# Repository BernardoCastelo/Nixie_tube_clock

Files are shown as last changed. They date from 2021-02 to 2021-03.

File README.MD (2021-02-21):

# Cold cathode display clock

## Components:
> - IN12 displays
> - Firebeetle ESP-32
> - NTE74141 BCD−to−Decimal Decoder
> - 74HC4094N 8-bit Shift Register

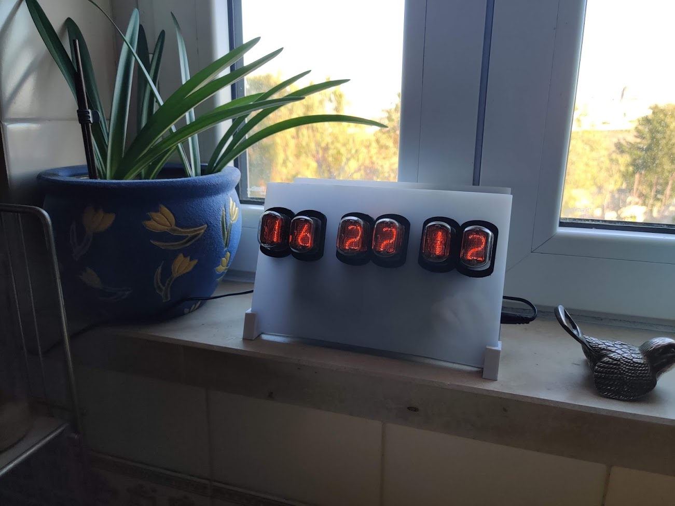
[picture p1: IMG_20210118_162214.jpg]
preview


- https://photos.app.goo.gl/ndDG4vCSE8pfqmn36

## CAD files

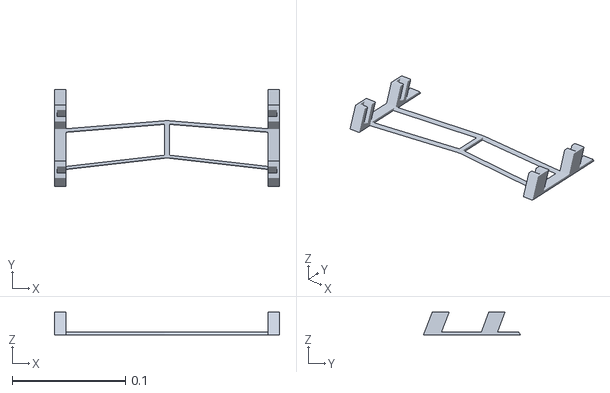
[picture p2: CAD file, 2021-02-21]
03.3DPrintedBase/Base.stl
0.199 x 0.0859 x 0.02

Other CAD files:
03.3DPrintedBase/Base.blend

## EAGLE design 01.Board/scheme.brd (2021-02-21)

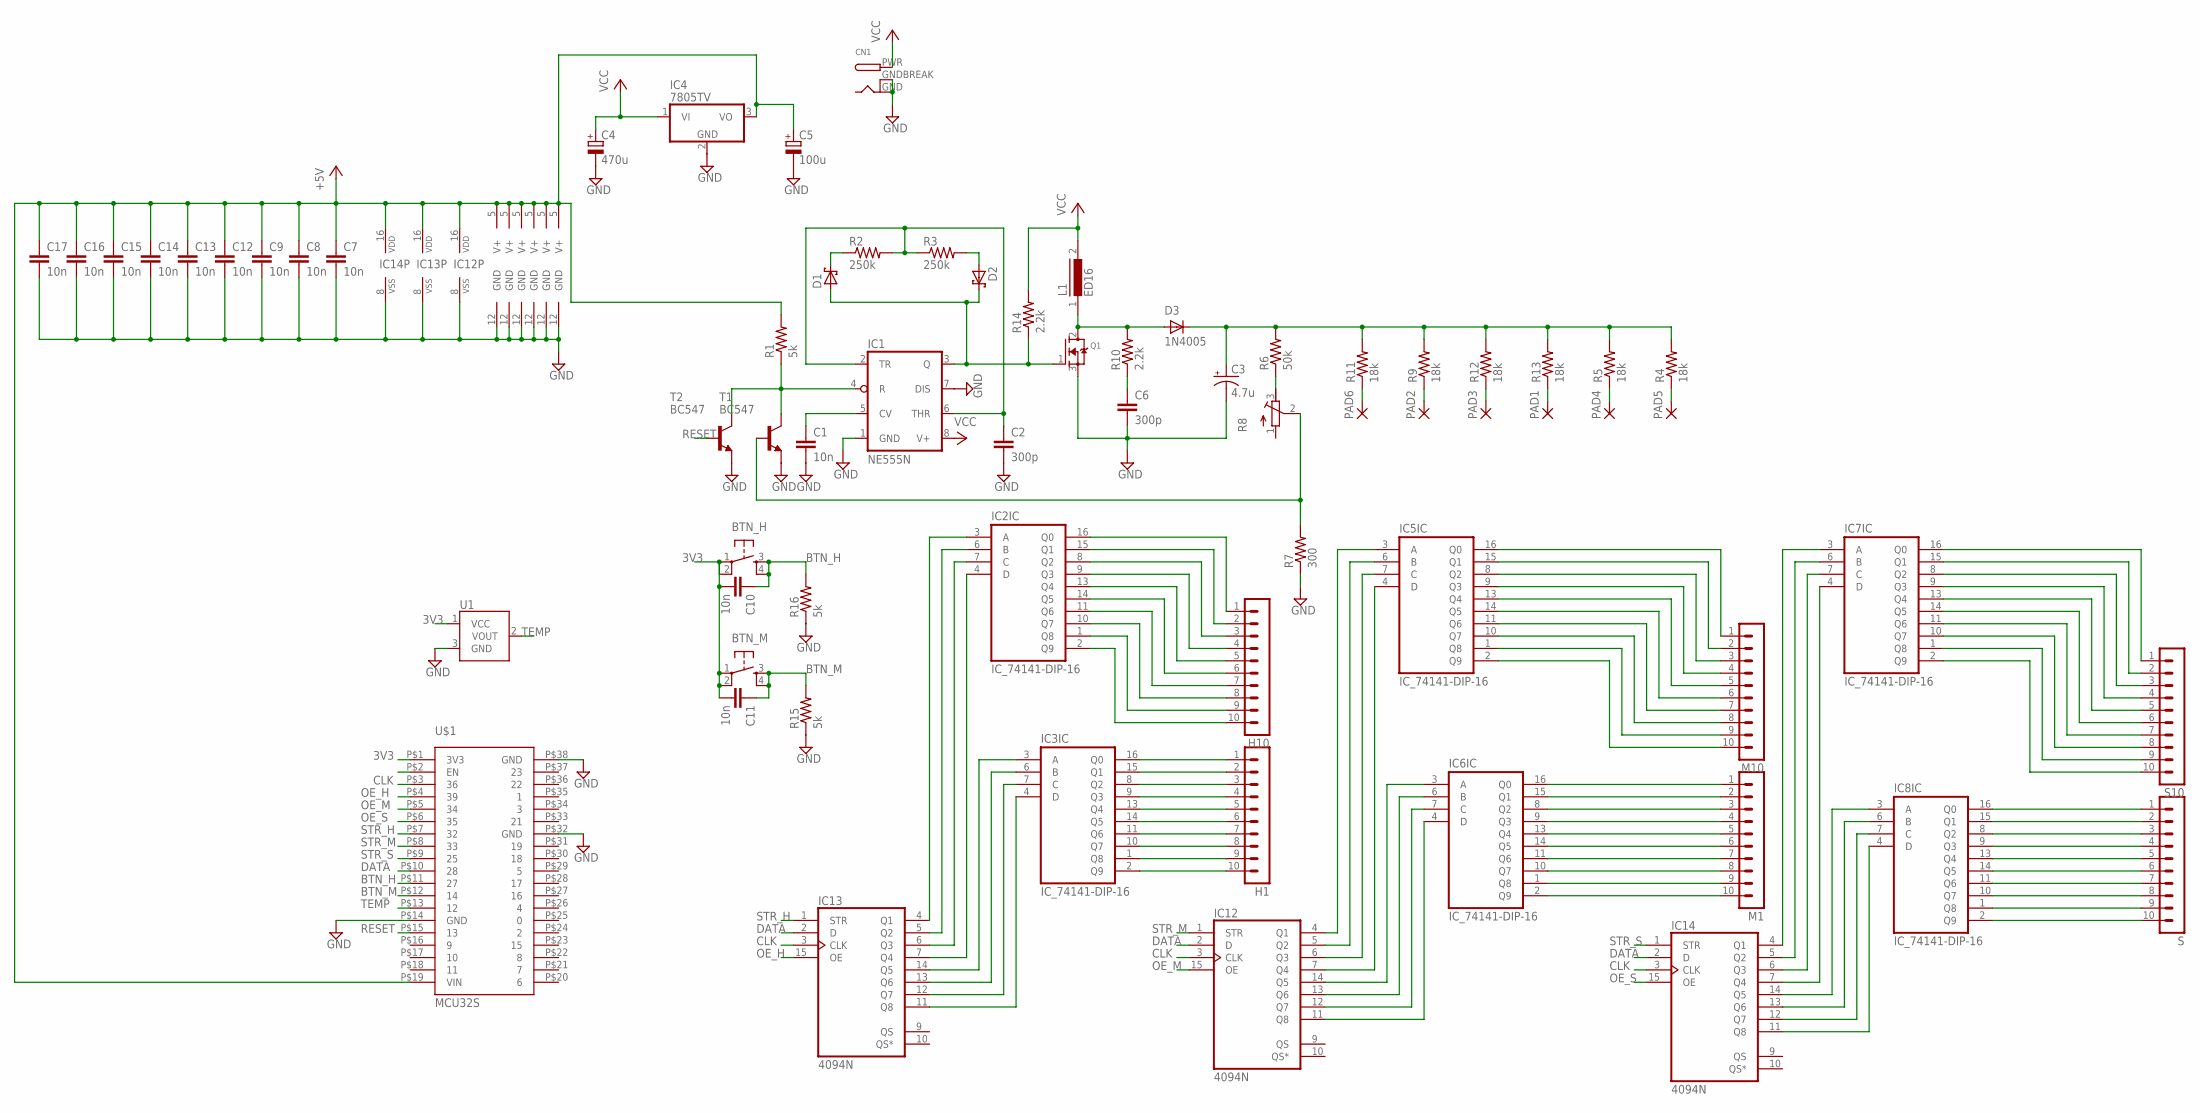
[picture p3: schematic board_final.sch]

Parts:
BTN_H: TAC_SWITCHPTH; TACTILE-PTH
BTN_M: TAC_SWITCHPTH; TACTILE-PTH
C1, C7, C8, C9, C10, C11, C12, C13, C14, C15, C16, C17: 10n; C050-030X075
C2, C6: 300p; C050-030X075
C3: 4.7u; E3,5-10
C4: 470u; E5-8,5
C5: 100u; E5-8,5
CN1: DCBARRELPTH; DCJACK_2MM_PTH
D1, D2: SCHOTTKY-DIODEF126Z12; F126Z12
D3: 1N4005; DO41-10
H1, H10: MA10-1
IC1: NE555N; DIL08
IC2, IC3, IC5, IC6, IC7, IC8: IC_74141-DIP-16; DIL16
IC4: 7805TV; TO220V
IC12, IC13, IC14: 4094N; DIL16
L1: ED16
M1, M10: MA10-1
PAD1, PAD2, PAD3, PAD4, PAD5, PAD6: 3,17/1,3
Q1: MOSFET-NGDS_TO220V; TO220V
R1, R15, R16: 5k; 0207/10
R2, R3: 250k; 0207/10
R4, R5, R9, R11, R12, R13: 18k; 0207/10
R6: 50k; 0207/10
R7: 300; 0207/10
R8: R-TRIMM3296W; RTRIM3296W
R10, R14: 2.2k; 0207/10
S, S10: MA10-1
T1, T2: BC547; TO92
U1: TMP36GT9; TO-92
U$1: MCU32S; NODEMCU32S

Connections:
3V3: BTN_H.1, BTN_H.2, BTN_M.1, BTN_M.2, C10.2, C11.2, U1.1 (VCC), U$1.P$1 (3V3)
BTN_H: BTN_H.3, BTN_H.4, C10.1, R16.2, U$1.P$11 (27)
BTN_M: BTN_M.3, BTN_M.4, C11.1, R15.2, U$1.P$12 (14)
CLK: IC12.3 (CLK), IC13.3 (CLK), IC14.3 (CLK), U$1.P$3 (36)
DATA: IC12.2 (D), IC13.2 (D), IC14.2 (D), U$1.P$10 (28)
GND: C1.2, C2.2, C3.-, C4.-, C5.-, C6.2, C7.2, C8.2, C9.2, C12.2, C13.2, C14.2, C15.2, C16.2, C17.2, CN1.GND, CN1.GNDBREAK, IC1.1 (GND), IC1.7 (DIS), IC2.12 (GND), IC3.12 (GND), IC4.2 (GND), IC5.12 (GND), IC6.12 (GND), IC7.12 (GND), IC8.12 (GND), IC12.8 (VSS), IC13.8 (VSS), IC14.8 (VSS), Q1.3 (S), R7.1, R15.1, R16.1, T1.1 (E), T2.1 (E), U1.3 (GND), U$1.P$14 (GND), U$1.P$32 (GND), U$1.P$38 (GND)
unnamed: C1.1, IC1.5 (CV)
unnamed: C2.1, IC1.2 (TR), IC1.6 (THR), R2.2, R3.1
unnamed: C3.+, D3.C, R4.2, R5.2, R6.2, R9.2, R11.2, R12.2, R13.2
unnamed: D1.A, D2.C, IC1.3 (Q), Q1.1 (G), R14.1
unnamed: IC1.4 (R), R1.1, T1.3 (C), T2.3 (C)
unnamed: H10.1, IC2.16 (Q0)
unnamed: D2.A, R3.2
unnamed: D1.C, R2.1
unnamed: IC2.3 (A), IC13.4 (Q1)
unnamed: D3.A, L1.1, Q1.2 (D), R10.2
unnamed: H10.2, IC2.15 (Q1)
unnamed: H10.3, IC2.8 (Q2)
unnamed: H10.4, IC2.9 (Q3)
unnamed: H10.5, IC2.13 (Q4)
unnamed: H10.6, IC2.14 (Q5)
unnamed: H10.7, IC2.11 (Q6)
unnamed: H10.8, IC2.10 (Q7)
unnamed: H10.9, IC2.1 (Q8)
unnamed: H10.10, IC2.2 (Q9)
unnamed: PAD6.1, R11.1
unnamed: IC2.7 (C), IC13.6 (Q3)
unnamed: IC2.6 (B), IC13.5 (Q2)
unnamed: IC2.4 (D), IC13.7 (Q4)
unnamed: H1.1, IC3.16 (Q0)
unnamed: H1.2, IC3.15 (Q1)
unnamed: H1.3, IC3.8 (Q2)
unnamed: C6.1, R10.1
unnamed: H1.4, IC3.9 (Q3)
unnamed: H1.5, IC3.13 (Q4)
unnamed: H1.6, IC3.14 (Q5)
unnamed: H1.7, IC3.11 (Q6)
unnamed: R6.1, R8.3 (E)
unnamed: R7.2, R8.2 (S), T1.2 (B)
unnamed: H1.8, IC3.10 (Q7)
unnamed: H1.9, IC3.1 (Q8)
unnamed: H1.10, IC3.2 (Q9)
unnamed: IC3.7 (C), IC13.12 (Q7)
unnamed: IC3.6 (B), IC13.13 (Q6)
unnamed: IC3.4 (D), IC13.11 (Q8)
unnamed: PAD2.1, R9.1
unnamed: IC3.3 (A), IC13.14 (Q5)
unnamed: IC6.2 (Q9), M1.10
unnamed: IC6.1 (Q8), M1.9
unnamed: IC6.10 (Q7), M1.8
unnamed: IC6.11 (Q6), M1.7
unnamed: IC6.14 (Q5), M1.6
unnamed: IC6.13 (Q4), M1.5
unnamed: IC6.9 (Q3), M1.4
unnamed: IC6.8 (Q2), M1.3
unnamed: IC6.15 (Q1), M1.2
unnamed: IC6.16 (Q0), M1.1
unnamed: IC5.7 (C), IC12.6 (Q3)
unnamed: IC5.6 (B), IC12.5 (Q2)
unnamed: IC5.4 (D), IC12.7 (Q4)
unnamed: PAD3.1, R12.1
unnamed: IC5.3 (A), IC12.4 (Q1)
unnamed: IC5.16 (Q0), M10.1
unnamed: IC5.15 (Q1), M10.2
unnamed: IC5.8 (Q2), M10.3
unnamed: IC5.9 (Q3), M10.4
unnamed: IC5.13 (Q4), M10.5
unnamed: IC5.14 (Q5), M10.6
unnamed: IC5.11 (Q6), M10.7
unnamed: IC5.10 (Q7), M10.8
unnamed: IC5.1 (Q8), M10.9
unnamed: IC5.2 (Q9), M10.10
unnamed: IC6.6 (B), IC12.13 (Q6)
unnamed: IC8.16 (Q0), S.1
unnamed: IC8.15 (Q1), S.2
unnamed: PAD1.1, R13.1
unnamed: IC6.3 (A), IC12.14 (Q5)
unnamed: IC7.3 (A), IC14.4 (Q1)
unnamed: IC8.8 (Q2), S.3
unnamed: IC8.9 (Q3), S.4
unnamed: IC8.13 (Q4), S.5
unnamed: IC8.14 (Q5), S.6
unnamed: IC8.11 (Q6), S.7
unnamed: IC8.10 (Q7), S.8
unnamed: IC8.2 (Q9), S.10
unnamed: IC8.1 (Q8), S.9
unnamed: IC7.16 (Q0), S10.1
unnamed: IC7.6 (B), IC14.5 (Q2)
unnamed: IC7.7 (C), IC14.6 (Q3)
unnamed: IC7.4 (D), IC14.7 (Q4)
unnamed: PAD4.1, R5.1
unnamed: IC8.3 (A), IC14.14 (Q5)
unnamed: IC8.6 (B), IC14.13 (Q6)
unnamed: IC7.15 (Q1), S10.2
unnamed: IC7.8 (Q2), S10.3
unnamed: IC7.9 (Q3), S10.4
unnamed: IC7.13 (Q4), S10.5
unnamed: IC7.14 (Q5), S10.6
unnamed: IC7.11 (Q6), S10.7
unnamed: IC7.10 (Q7), S10.8
unnamed: IC7.1 (Q8), S10.9
unnamed: IC7.2 (Q9), S10.10
unnamed: IC8.7 (C), IC14.12 (Q7)
unnamed: IC8.4 (D), IC14.11 (Q8)
unnamed: PAD5.1, R4.1
unnamed: IC6.7 (C), IC12.12 (Q7)
unnamed: IC6.4 (D), IC12.11 (Q8)
OE_H: IC13.15 (OE), U$1.P$4 (39)
OE_M: IC12.15 (OE), U$1.P$5 (34)
OE_S: IC14.15 (OE), U$1.P$6 (35)
RESET: T2.2 (B), U$1.P$15 (13)
STR_H: IC13.1 (STR), U$1.P$7 (32)
STR_M: IC12.1 (STR), U$1.P$8 (33)
STR_S: IC14.1 (STR), U$1.P$9 (25)
TEMP: U1.2 (VOUT), U$1.P$13 (12)
V+: C5.+, C7.1, C8.1, C9.1, C12.1, C13.1, C14.1, C15.1, C16.1, C17.1, IC2.5 (V+), IC3.5 (V+), IC4.3 (VO), IC5.5 (V+), IC6.5 (V+), IC7.5 (V+), IC8.5 (V+), IC12.16 (VDD), IC13.16 (VDD), IC14.16 (VDD), R1.2, U$1.P$19 (VIN)
VCC: C4.+, CN1.PWR, IC1.8 (V+), IC4.1 (VI), L1.2, R14.2

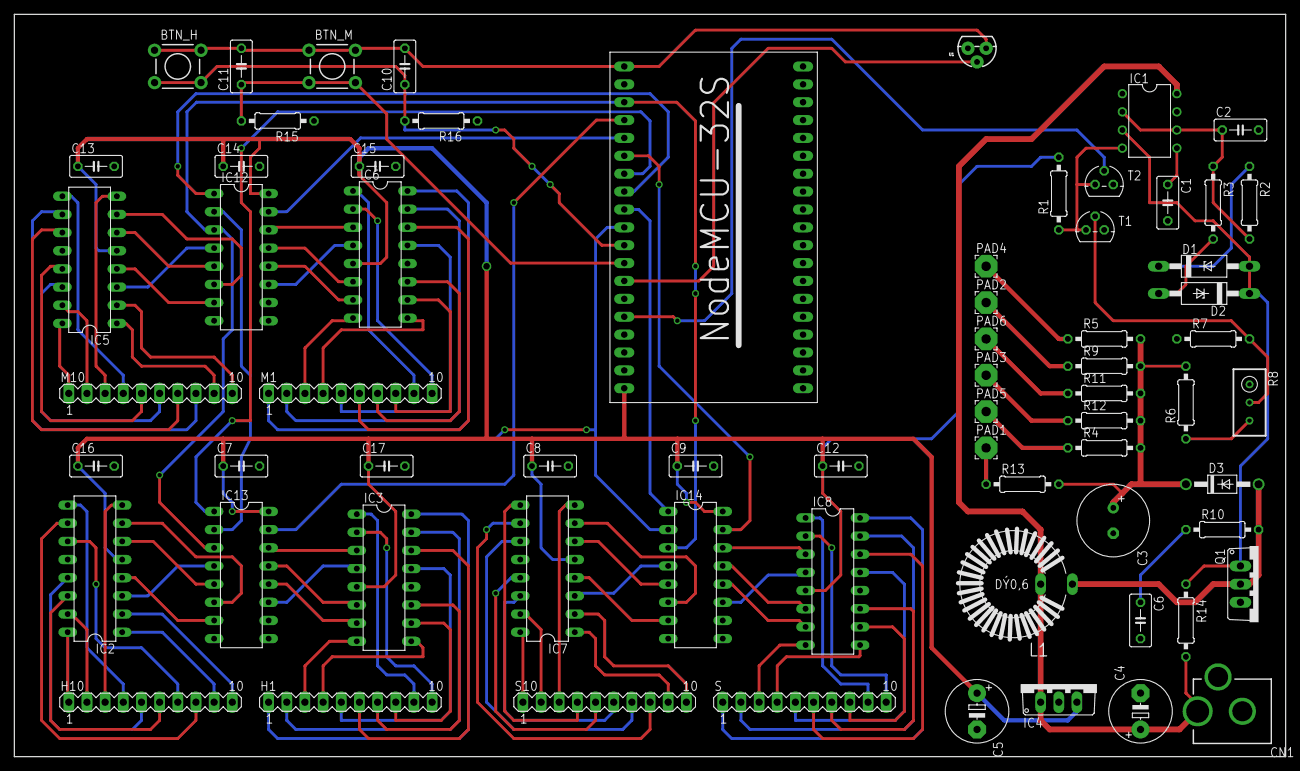
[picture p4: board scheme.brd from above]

Board: 2 copper layers, 177.8 x 103.8 mm, 68 parts (0 on the bottom side), 117 nets.

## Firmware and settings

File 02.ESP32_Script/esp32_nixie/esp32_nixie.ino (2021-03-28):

#include <WiFi.h>
#include "time.h"
#include "constsLib.h"

struct tm timeinfo;
volatile byte hours;
volatile byte minutes;
volatile byte seconds;
volatile int millisValue = 0;
volatile int ntpMillisValue = 0;
volatile bool isShufflingSeconds = false;
volatile bool isShufflingMinutes = false;
volatile bool isShufflingHours = false;
volatile bool isConnecting = false;
volatile int tmpCalc;

void setup()
{
  Serial.begin(9600);
  pinMode(OE_H, OUTPUT);
  pinMode(OE_M, OUTPUT);
  pinMode(OE_S, OUTPUT);
  digitalWrite(OE_H, HIGH);
  digitalWrite(OE_M, HIGH);
  digitalWrite(OE_S, HIGH);

  pinMode(CLK_PIN, OUTPUT);
  pinMode(STR_H, OUTPUT);
  pinMode(STR_M, OUTPUT);
  pinMode(STR_S, OUTPUT);
  pinMode(DATA_PIN, OUTPUT);
  pinMode(RESET, OUTPUT);

  pinMode(BTN_H, INPUT);
  pinMode(BTN_M, INPUT);
  pinMode(TEMP_PIN, INPUT);

  digitalWrite(CLK_PIN, LOW);
  digitalWrite(STR_H, LOW);
  digitalWrite(STR_M, LOW);
  digitalWrite(STR_S, LOW);
  digitalWrite(DATA_PIN, LOW);

  WiFi.begin(ssid, password);
  while (WiFi.status() != WL_CONNECTED)
  {
    delay(500);
    Serial.print(".");
  }
  Serial.println(" CONNECTED");

  configTime(gmtOffset_sec, daylightOffset_sec, ntpServer);
  while (!getLocalTime(&timeinfo))
  {
    Serial.println("Failed to obtain time");
  }

  updateTime();

  WiFi.disconnect(true);
  WiFi.mode(WIFI_OFF);

  digitalWrite(OE_H, LOW);
  digitalWrite(OE_M, LOW);
  digitalWrite(OE_S, LOW);
}

void loop()
{
  if (isShufflingSeconds)
  {
    writeDisplay(SECOND, random(0, 99));
  }

  if (isShufflingMinutes)
  {
    writeDisplay(MINUTE, random(0, 99));
  }

  if (isShufflingHours)
  {
    writeDisplay(HOUR, random(0, 99));
  }
  delay(10);
  if (hours == 2)
    updateTime();

  /*
     Synchronous (dumb) time counter and minute/hour calculator,
     as is it deviates about 1 minute for every 6H.
  */
  if (millis() - millisValue > 995)
  {
    millisValue = millis();
    seconds++;
    shuffle();
    if (seconds >= 60)
    {
      seconds = 0;
      minutes++;

      if (minutes >= 60)
      {
        minutes = 0;
        hours++;

        if (hours >= 24)
        {
          hours = 0;
        }
      }
    }
    writeDisplay(SECOND, seconds);
    writeDisplay(MINUTE, minutes);
    writeDisplay(HOUR, hours);
  }

  /*
     NTP Getter region, get the time from a ntp server specified in "ntpServer" with a periodicity of "ntpGetPeriod" miliseconds.
  */
  tmpCalc = millis() - ntpMillisValue;
  if (tmpCalc > ntpGetPeriod || isConnecting)
  {
    ntpMillisValue = millis();
    if (tmpCalc - ntpGetPeriod > 60000)
    { // If it fails after 60s, retry again in the next period
      finishNtpGetter();
      return;
    }
    if (!isConnecting)
    {
      WiFi.begin(ssid, password);
      isConnecting = true;
    }
    if (WiFi.status() == WL_CONNECTED)
    {
      updateTime();
      finishNtpGetter();
    }
  }
}

void finishNtpGetter()
{
  WiFi.disconnect(true);
  WiFi.mode(WIFI_OFF);
  isConnecting = false;
  ntpMillisValue = millis();
}

void shuffle()
{
  if (!isShufflingMinutes)
  {
    isShufflingHours = false;
  }
  if (!isShufflingSeconds)
  {
    isShufflingMinutes = false;
  }
  if (minutes == 15)
  { // Shuffles every hour.
    isShufflingSeconds = true;
    isShufflingMinutes = true;
    isShufflingHours = true;
  }
  else
  {
    isShufflingSeconds = false;
  }
}

/*
   ex: 26 = 0001 1010‬
   decadeSeparator(26) = 0110  0010
                         (6)   (2)
*/
byte decadeSeparator(byte num)
{
  byte separated = num - (num / 10) * 10;
  separated--;
  if (separated < 0 || separated > 9)
    separated = 9;
  separated = separated << 4;
  byte dec = num / 10 - 1;
  if (dec < 0 || dec > 9)
    dec = 9;
  separated = separated + dec;
  return separated;
}

/*
    h - hours
    m - minutes
    s - seconds
*/
void writeDisplay(DigitType type, byte value)
{
  value = decadeSeparator(value);
  byte bitSelector = 0b10000000;
  bool val = false;
  digitalWrite(STR_H, type == HOUR);
  digitalWrite(STR_M, type == MINUTE);
  digitalWrite(STR_S, type == SECOND);
  for (int i = 0; i < 8; i++)
  {
    val = value & bitSelector;
    digitalWrite(DATA_PIN, val);
    digitalWrite(CLK_PIN, LOW);
    delay(CLK);
    digitalWrite(CLK_PIN, HIGH);
    delay(CLK);
    digitalWrite(CLK_PIN, LOW);
    bitSelector = bitSelector >> 1;
  }
}

void updateTime()
{
  if (getLocalTime(&timeinfo))
  {
    int day = timeinfo.tm_mday;
    int month = timeinfo.tm_mon + 1;
    int dayOfTheWeek = timeinfo.tm_wday;
    int remainingDays = day - 25;

    if (month > 3 && month < 10)
    {
      daylightOffset_sec = 3600;
    }

    if (month > 10 && month < 3)
    {
      daylightOffset_sec = 0;
    }

    if (month == 3 && day > 24 && dayOfTheWeek <= remainingDays)
    {
      daylightOffset_sec = 3600;
    }

    if (month == 10 && day > 24 && dayOfTheWeek <= remainingDays)
    {
      daylightOffset_sec = 0;
    }
    configTime(gmtOffset_sec, daylightOffset_sec, ntpServer);
  }
  while (!getLocalTime(&timeinfo))
  {
    configTime(gmtOffset_sec, daylightOffset_sec, ntpServer);
  }
  hours = timeinfo.tm_hour;
  minutes = timeinfo.tm_min;
  seconds = timeinfo.tm_sec;
}

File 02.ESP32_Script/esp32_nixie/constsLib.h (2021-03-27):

#define CLK_PIN 22
#define CLK 0
#define OE_H 39
#define OE_M 34
#define OE_S 35
#define STR_H 32
#define STR_M 33
#define STR_S 25
#define DATA_PIN 26
#define BTN_H 27
#define BTN_M 14
#define TEMP_PIN 12
#define RESET 13
#define OFF_CODE 0b1111

const char *ssid = "";
const char *password = "";
const char *ntpServer = "pool.ntp.org";
const long gmtOffset_sec = 0;
int daylightOffset_sec = 0;
const int ntpGetPeriod = 18000000;
enum DigitType
{
  SECOND,
  MINUTE,
  HOUR
};

void writeDisplay(DigitType type, byte value);

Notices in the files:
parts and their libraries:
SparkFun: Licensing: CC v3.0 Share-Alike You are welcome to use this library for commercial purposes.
